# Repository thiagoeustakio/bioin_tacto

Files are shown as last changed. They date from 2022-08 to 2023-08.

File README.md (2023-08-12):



# BioIn-Tacto: A Compliant Multimodal Tactile Sensing Module
Hardware X journal paper: [BioIn-Tacto: A Compliant Multimodal Tactile Sensing Module]()

How to cite this repository:

    @software{thiago_eustaquio_alves_de_oliveira_2022_7011242,
      author       = {Thiago Eustaquio Alves de Oliveira and
                      Vinicius Prado da Fonseca},
      title        = {{BioIn-Tacto: tactile sensing module design files 
                       and source code.}},
      month        = aug,
      year         = 2022,
      publisher    = {Zenodo},
      version      = {v1.0.0},
      doi          = {10.5281/zenodo.7011242},
      url          = {https://doi.org/10.5281/zenodo.7011242}
    }

## Overview

This repository contain firmware, ROS code and CAD files for the multimodal tactile sensor. The packages have been tested under ROS Melodic and Ubuntu 18.04 LTS.

- ROS code is in the [bioin_tacto_ws](bioin_tacto_ws/) folder.  
- Sensor building CAD files are upload in the [CAD](CAD/) folder.  
- Firmware files are available in the [firmware](firmware/) folder.

This sensing module was developed with a focus on the compliant structure and skin deformation. This module is a research platform that can be built at a lower price (approximately **USD$ 35.00**, using only 3D printing) than other similar sensors. Moreover, it was designed to capture the skin deformation not available on most tactile sensors in the market.

**Authors: [Thiago Eustaquio Alves de Oliveira](https://www.linkedin.com/in/teado/), talvesd@lakeheadu.ca and [Vinicius Prado da Fonseca](https://www.cs.mun.ca/~vpradodafons/), vpradodafons@mun.ca**

**Affiliation: Department of Computer Science, [Lakehead University](https://www.lakeheadu.ca/), Canada; Department of Computer Science [Memorial University of Newfoundland](https://www.mun.ca/), Canada**

## Installation
- Before do this, please backup important files.
- After following building instructions found in Section 5 from the Hardware X journal paper, [BioIn-Tacto: A Compliant Multimodal Tactile Sensing Module]() you should have a working sensor module that requires a firmware upload to the MCU for serial communication with the main computer.

### Dependencies

- Tested using Ubuntu 18.04.
- Tested using Teensy 4.0 MCU.

## Firmware Installation

The firmware requires the Arduino environemnt and ROS messages from the [bioin_tacto_ws](bioin_tacto_ws/). The following section covers, Arduino, teensyduino, ROS messages and firmware upload instructions.

## Install Arduino and Teensyduino
Follow the **Command Line Install** instructions below, also available [here](https://www.pjrc.com/teensy/td_download.html).

    $ wget https://downloads.arduino.cc/arduino-1.8.15-linux64.tar.xz
    $ wget https://www.pjrc.com/teensy/td_154/TeensyduinoInstall.linux64
    $ wget https://www.pjrc.com/teensy/00-teensy.rules
    $ sudo cp 00-teensy.rules /etc/udev/rules.d/
    $ tar -xf arduino-1.8.15-linux64.tar.xz
    $ chmod 755 TeensyduinoInstall.linux64
    $ ./TeensyduinoInstall.linux64 --dir=arduino-1.8.15
    $ cd arduino-1.8.15/hardware/teensy/avr/cores/teensy4
    $ make

## Install ROS (Melodic) tested on Ubuntu 18.04
This software is built on the Robotic Operating System ([ROS](http://wiki.ros.org/ROS/Installation)).   
Follow **Desktop-Full Install: (Recommended)** below, also available [here](http://wiki.ros.org/melodic/Installation/Ubuntu).

    $ sudo sh -c 'echo "deb http://packages.ros.org/ros/ubuntu $(lsb_release -sc) main" > /etc/apt/sources.list.d/ros-latest.list'
    $ sudo apt install curl
    $ curl -s https://raw.githubusercontent.com/ros/rosdistro/master/ros.asc | sudo apt-key add -
    $ sudo apt update
    $ sudo apt upgrade
    $ sudo apt install ros-melodic-desktop-full 
    $ echo "source /opt/ros/melodic/setup.bash" >> ~/.bashrc
    $ source ~/.bashrc
    $ sudo apt install python-rosdep python-rosinstall python-rosinstall-generator python-wstool build-essential
    $ sudo apt install python-rosdep
    $ sudo rosdep init
    $ rosdep update

## Compile the ros `bioin_tacto_ws` and messages

    $ cd <repository_folder>/bioin_tacto_ws/
    $ catkin_make
    $ source devel/setup.bash

## Generate arduino `ros_lib` library with ROS messages from workspace

    $ cd <arduino_directory>/libraries
    $ rm -rf ros_lib
    $ rosrun rosserial_arduino make_libraries.py .

## Tactile module firmware instalation

- Copy firmware/lib/**MPL115A2MUX** folder to `<arduino_directory>/libraries`
- Copy firmware/lib/**LSMMUX** folder to `<arduino_directory>/libraries`
- Copy firmware/lib/**SparkFun_BNO080_Cortex_Based_IMU** folder to `<arduino_directory>/libraries`
- Inside the arduino environemnt open the **firmware/bioin-tacto-firmware/LSM9DS0/bioin-tacto-firmware/bioin-tacto-firmware.ino** file, compile and upload to the teensy
- OR, if you are using the BNO08X Custom MARG, open the **firmware/bioin-tacto-firmware/BNO08X/bioin-tacto-firmware_BNO08X/bioin-tacto-firmware_BNO08X.ino** file in the arduino environemnt, compile and upload to the teensy

This firmware was tested using [teensy 4.0](https://www.pjrc.com/store/teensy40.html)

## How to start?
Launch the module nodes and visualization

    $ roslaunch bioin_tacto cell0.launch
    OR
    $ roslaunch bioin_tacto cell0_BNO08X.launch

## Description

### Visualize sensor data with `rqt` or `rostopic list`

The following topics are available in rqt (rostopic list)

    $ rostopic list
    /imu/data
    /imu/data_raw
    /imu/mag
    /m_imus_bias_removed
    /m_imus_serial
    /raw_barometers_teensy
    /raw_imus_teensy
    /tf

### Visualize sensor data with `rviz`

RViz will open automatically after the cell0.launch is launched.
You can visualize the frames of refence and pressure level on a rviz marker.

## Validation and Characterization

- The multimodal tactile sensor validation and characterization, click image to the YouTube video.

    [validation and characterization video validation and characterization](https://www.youtube.com/watch?v=z54BdTZGDCY)
    
## Demo

- The multimodal tactile sensor used in surface reconstruction, click image to the YouTube video.

    [surface reconstruction video](https://www.youtube.com/watch?v=32RQCK06KM0)

## License

See LICENSE file.

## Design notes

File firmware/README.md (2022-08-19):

## Compiling and Upload firmware to MCU.

Works with Arduino 1.8.13 and Teensyduino 1.53, or VSCode+PlatformIO!

First, generate `ros_lib` libraries from your catkin_workspace.

    $ source devel/setup.bash
    $ rosrun rosserial_arduino make_libraries.py .

Copy `ros_lib` directory to arduino library directory.
Compile `bioin-tacto-firmware.ino`, upload it to your MCU.

Run using:

    $ rosrun rosserial_python serial_node.py _baud:=250000 _port:=/dev/ttyACM0

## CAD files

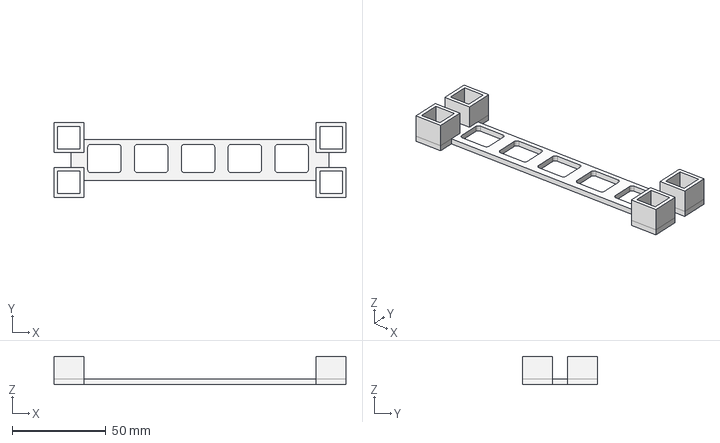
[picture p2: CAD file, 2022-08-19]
CAD/STEP/5_baro_bonding_holder.step
156.0 x 40.0 x 15.0 mm

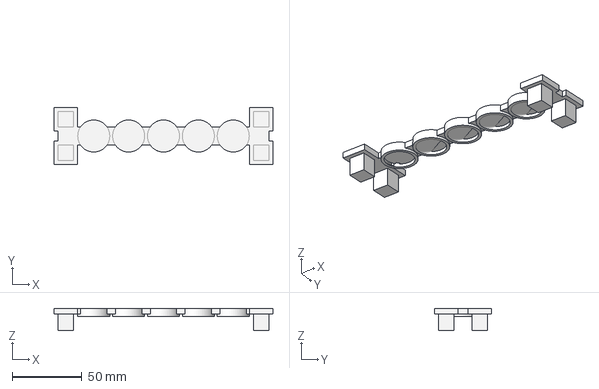
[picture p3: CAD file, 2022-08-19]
CAD/STEP/5_marg_bonding_holder.step
157.0 x 41.0 x 16.0 mm

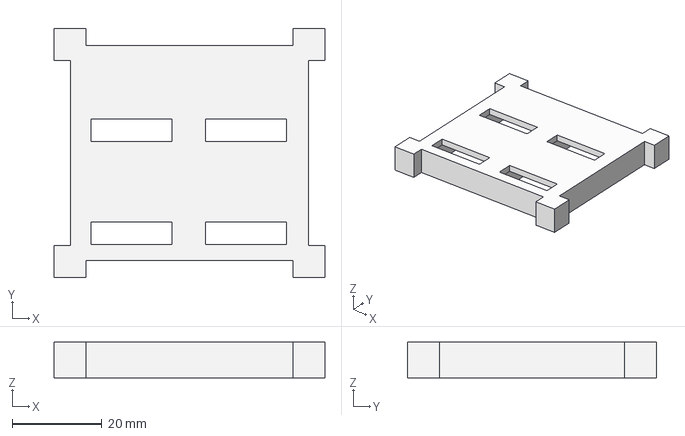
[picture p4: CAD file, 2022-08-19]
CAD/STEP/4_baro_holder.step
60.3 x 55.3 x 8.00 mm

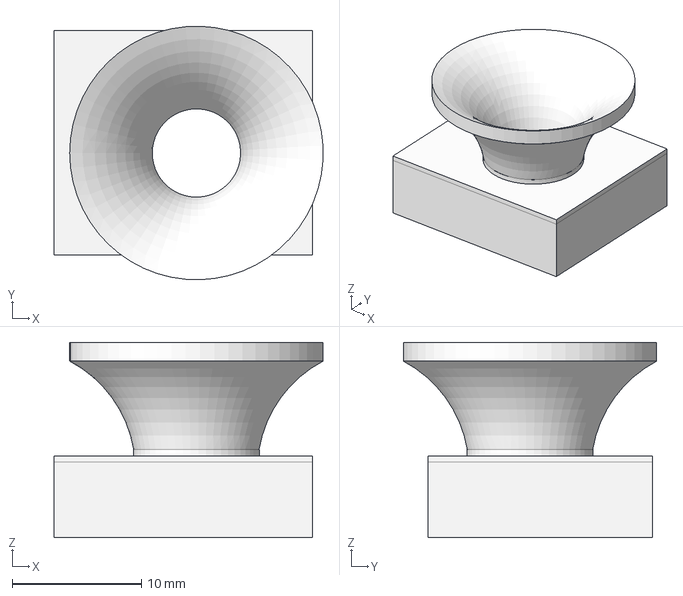
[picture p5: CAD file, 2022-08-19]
CAD/STEP/comp_struct_mold.step
20.8 x 19.6 x 15.1 mm

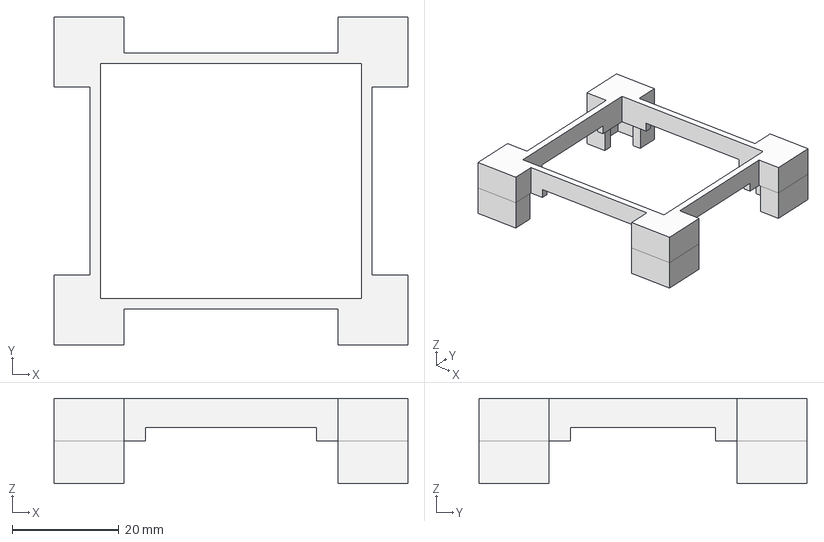
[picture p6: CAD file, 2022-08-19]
CAD/STEP/4_baro_holder_foot.step
66.3 x 61.3 x 16.0 mm

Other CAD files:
CAD/STL/4_baro_holder.stl
CAD/STL/4_baro_holder_foot.stl
CAD/STL/5_baro_bonding_holder.stl
CAD/STL/5_marg_bonding_holder.stl
CAD/STL/comp_struct_mold.stl

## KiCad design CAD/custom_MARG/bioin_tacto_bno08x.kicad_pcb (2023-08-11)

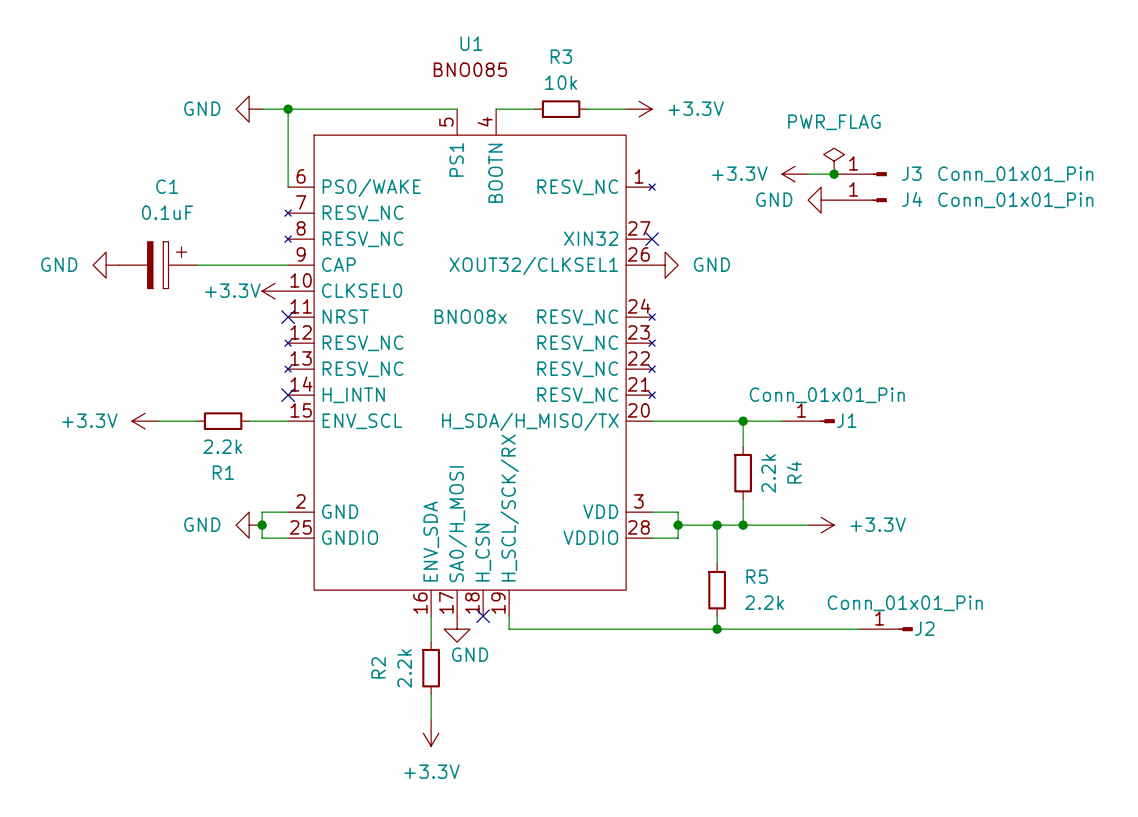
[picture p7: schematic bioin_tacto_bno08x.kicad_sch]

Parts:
C1: 0.1uF; C_0402_1005Metric
J1, J2, J3, J4: Conn_01x01_Pin; PinHeader_1x01_P1.00mm_Vertical
R1, R2, R4, R5: 2.2k; R_0402_1005Metric
R3: 10k; R_0402_1005Metric
U1: BNO08x; LGA-28_5.2x3.8mm_P0.5mm

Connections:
+3.3V: J3.1, R1.1, R2.2, R3.2, R4.2, R5.1, U1.3 (VDD), U1.10 (CLKSEL0), U1.28 (VDDIO)
GND: C1.2, J4.1, U1.2 (GND), U1.5 (PS1), U1.6 (PS0/WAKE), U1.17 (SA0/H_MOSI), U1.25 (GNDIO), U1.26 (XOUT32/CLKSEL1)
unnamed: J1.1, R4.1, U1.20 (H_SDA/H_MISO/TX)
unnamed: J2.1, R5.2, U1.19 (H_SCL/SCK/RX)
unnamed: R3.1, U1.4 (BOOTN)
unnamed: C1.1, U1.9 (CAP)
unnamed: R1.2, U1.15 (ENV_SCL)
unnamed: R2.1, U1.16 (ENV_SDA)

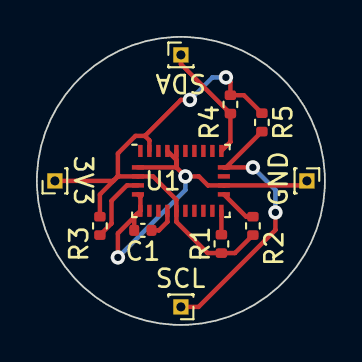
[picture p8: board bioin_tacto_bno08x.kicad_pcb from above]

Board: 2 copper layers, 16.0 x 16.0 mm, 11 parts (0 on the bottom side), 8 nets.

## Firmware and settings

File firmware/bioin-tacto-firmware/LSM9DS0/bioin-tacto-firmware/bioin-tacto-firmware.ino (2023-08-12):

//#define USE_TEENSY_HW_SERIAL

#include <ros.h>
#include <ros/time.h>
#include <bioin_tacto/raw_barometer.h>
#include <bioin_tacto/raw_imu.h>

ros::NodeHandle nh;

// #include <i2c_t3.h> //teensy 3.6- alternative to Wire
#include <Wire.h> // I2C functionality for Arduinos and Teensy4.0
#include <MPL115A2MUX.h>
#include <LSMMUX.h>

#define NUM_SENSORS 1

#define LSM9DS0_XM 0x1D // Would be 0x1E if SDO_XM is LOW
#define LSM9DS0_G 0x6B  // Would be 0x6A if SDO_G is LOW

MPL115A2MUX mpl115a2(NUM_SENSORS);

short sensorID = 0;
uint16_t status[NUM_SENSORS];

LSM9DS0 dof(MODE_I2C, LSM9DS0_G, LSM9DS0_XM);

bioin_tacto::raw_barometer rbaro;
bioin_tacto::raw_imu rimu;
ros::Publisher rir_reads("raw_imus_teensy", &rimu);
ros::Publisher rbr_reads("raw_barometers_teensy", &rbaro);

long seq = 0;
float pressure = 0, tempe = 0;

void setup()
{
  //  When using more than one module,
  //  the following lines set the state of the multiplex pins
  //
  //  pinMode(S0, OUTPUT);
  //  pinMode(S1, OUTPUT);
  //  pinMode(S2, OUTPUT);
  //  pinMode(S3, OUTPUT);
  //  digitalWrite(S0, LOW);
  //  digitalWrite(S1, LOW);
  //  digitalWrite(S2, LOW);
  //  digitalWrite(S3, LOW);
  pinMode(13, OUTPUT);

  digitalWrite(13, HIGH);
  delay(750);
  digitalWrite(13, LOW);
  delay(750);

  mpl115a2.begin();
  mpl115a2.upateSensorLevelID(0);

  status[sensorID] = dof.beginID(sensorID);
  dof.setAccelScale(dof.A_SCALE_2G);
  dof.setAccelODR(dof.A_ODR_200);
  dof.setAccelABW(dof.A_ABW_50);
  dof.setGyroScale(dof.G_SCALE_245DPS);
  dof.setGyroODR(dof.G_ODR_190_BW_125);
  dof.setMagScale(dof.M_SCALE_2GS);
  dof.setMagODR(dof.M_ODR_125);

  // Configure serial and ros node baud
  Serial.begin(250000);
  nh.getHardware()->setBaud(250000);

  nh.initNode();
  rbaro.header.frame_id = "baros_frames";
  nh.advertise(rbr_reads);

  rimu.header.frame_id = "imus_frames";
  nh.advertise(rir_reads);

  delay(5);

  digitalWrite(13, HIGH);
}

void loop()
{
  for (int sensorID = 0; sensorID < NUM_SENSORS; sensorID++)
  {
    mpl115a2.upateSensorLevelID(sensorID);
    rbaro.sensor_id = sensorID;
    rbaro.baro_level = mpl115a2.pressureHistory[sensorID];
    rbaro.tempe = tempe;
    rbaro.header.seq = seq;
    rbaro.header.stamp = nh.now();
    rbr_reads.publish(&rbaro);
    nh.spinOnce();
  }

  for (int sensorID = 0; sensorID < NUM_SENSORS; sensorID++)
  {
    dof.readMux(sensorID);

    rimu.sensor_id = sensorID;
    dof.readGyro(sensorID);
    rimu.gx = (float)(dof.calcGyro(dof.gx[sensorID]));
    rimu.gy = (float)(dof.calcGyro(dof.gy[sensorID]));
    rimu.gz = (float)(dof.calcGyro(dof.gz[sensorID]));

    dof.readAccel(sensorID);
    rimu.ax = (float)(dof.calcAccel(dof.ax[sensorID]));
    rimu.ay = (float)(dof.calcAccel(dof.ay[sensorID]));
    rimu.az = (float)(dof.calcAccel(dof.az[sensorID]));

    dof.readMag(sensorID);
    rimu.mx = dof.calcMag(dof.mx[sensorID]);
    rimu.my = dof.calcMag(dof.my[sensorID]);
    rimu.mz = dof.calcMag(dof.mz[sensorID]);

    dof.readTemp(sensorID);
    rimu.tempe = 21.0 + (float)dof.temperature[sensorID] / 8.;

    rimu.header.seq = seq;
    rimu.header.stamp = nh.now();
    rir_reads.publish(&rimu);
    nh.spinOnce();
  }

  seq++;
}

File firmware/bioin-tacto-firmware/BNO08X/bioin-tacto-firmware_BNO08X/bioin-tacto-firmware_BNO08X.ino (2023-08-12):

//#define USE_TEENSY_HW_SERIAL
#include <ros.h>
#include <ros/time.h>
#include <bioin_tacto/raw_barometer.h>
#include <bioin_tacto/raw_imu.h>

byte accAccuracy = 0;
byte gyroAccuracy = 0;
byte magAccuracy = 0;
float ax, ay, az, gx, gy, gz, mx, my, mz;

ros::NodeHandle nh;

#include <Wire.h> // I2C functionality for Arduinos and Teensy4.0
#include <MPL115A2MUX.h>
#include "SparkFun_BNO080_Arduino_Library.h" // Click here to get the library: http://librarymanager/All#SparkFun_BNO080

#define NUM_SENSORS 1

BNO080 myMARG;
MPL115A2MUX mpl115a2(NUM_SENSORS);

short sensorID = 0;
uint16_t status[NUM_SENSORS];

bioin_tacto::raw_barometer rbaro;
bioin_tacto::raw_imu rimu;
ros::Publisher rir_reads("raw_imus_teensy", &rimu);
ros::Publisher rbr_reads("raw_barometers_teensy", &rbaro);

long seq = 0;
float pressure = 0, tempe = 21;

void setup()
{ 
  //  When using more than one module,
  //  the following lines set the state of the multiplex pins
  //
  //  pinMode(S0, OUTPUT);
  //  pinMode(S1, OUTPUT);
  //  pinMode(S2, OUTPUT);
  //  pinMode(S3, OUTPUT);
  //  digitalWrite(S0, LOW);
  //  digitalWrite(S1, LOW);
  //  digitalWrite(S2, LOW);
  //  digitalWrite(S3, LOW);
  // Configure serial and ros node baud
  Serial.begin(250000);
  nh.getHardware()->setBaud(250000);

  pinMode(13, OUTPUT);

  digitalWrite(13, HIGH);
  delay(750);
  digitalWrite(13, LOW);
  delay(750);

 
  Wire.begin();
  delay(50);
  while (myMARG.begin() == false)
  {
//    while(1){
//          Serial.println("ERROR, CHECK WIRING");
          delay(3);
//    }
  }
//  Serial.println("Success");
  Wire.setClock(400000); //Increase I2C data rate to 400kHz
  myMARG.enableAccelerometer(1); // m/s^2 no plus gravity
  myMARG.enableGyro(1);  // rad/s
  myMARG.enableMagnetometer(1);


  mpl115a2.begin();
  mpl115a2.upateSensorLevelID(0);

  nh.initNode();

  rimu.header.frame_id = "imus_frames";
  nh.advertise(rir_reads);

  rbaro.header.frame_id = "baros_frames";
  nh.advertise(rbr_reads);

  delay(5);
 
  digitalWrite(13, HIGH);
}

void loop()
{
    for (int sensorID = 0; sensorID < NUM_SENSORS; sensorID++)
    {
      mpl115a2.upateSensorLevelID(sensorID);
      rbaro.sensor_id = sensorID;
      rbaro.baro_level = mpl115a2.pressureHistory[sensorID];
      rbaro.tempe = tempe;
      rbaro.header.seq = seq;
      rbaro.header.stamp = nh.now();
      rbr_reads.publish(&rbaro);
      nh.spinOnce();
    }
    
    rimu.sensor_id = sensorID;

    if (myMARG.dataAvailable() == true)
      {
        myMARG.getAccel(ax, ay, az, accAccuracy);
        rimu.ax=ax; rimu.ay=ay; rimu.az=az;
        myMARG.getGyro(gx, gy, gz, gyroAccuracy);
        rimu.gx=gx; rimu.gy=gy; rimu.gz=gz;
        myMARG.getMag(mx, my, mz, magAccuracy);
        rimu.mx=mx; rimu.my=my; rimu.mz=mz;
      
        rimu.tempe = tempe;
    
        rimu.header.seq = seq;
        rimu.header.stamp = nh.now();
        rir_reads.publish(&rimu);
        nh.spinOnce();
    }
  seq++;
}
